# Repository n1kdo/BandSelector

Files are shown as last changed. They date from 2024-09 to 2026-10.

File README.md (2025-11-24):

# N1KDO IOT Band Selector for Elecraft K3 & K4 

This project is intended to operate a remote antenna switch.

How is it different from commercial-off-the-shelf solutions?
* Direct interface with Elecraft 15-Pin accessory interface. It reads
  BCD band data using the Elecraft Y-cable or a device like a Y-box.
  * provides transmit inhibit and power-on sense/control.
  * it's not designed for other radios.  Tested on Elecraft only. It _should_ 
    work with other radios that use similar BCD active low band signaling. 
* Wireless! It runs over Wi-Fi, connect the band selector to 
  the 15-pin accessory connector, and supply DC to the coaxial
  power jack. 
* Automatic TX Inhibit prevents TX into wrong/no antenna.
* Automatic power-up of K3 and K4 radios using accessory connector pin.  The
  band selector can be configured to automatically power up a attached K3 or K4 
  10 seconds after the Band Selector powers up.
* Smart antenna selection based on band.  If you have more than one antenna
  for a given band, the logic selects the antenna that matches the fewest
  other bands, which is hopefully the best fit.  If that antenna is in use by
  the other radio, then it selects the next-best match.  When more than one
  antenna is available for the given band, the front panel Next/Prev buttons
  let you select other antennas that support the selected band.
* Inexpensive (relatively) compared to existing commercial solutions. 
  About 77 USD for each band selector, if you build one or two yourself.
  (Circuit boards come in threes from Oshpark.)  The 
  [Antenna Switch Controller](https://github.com/n1kdo/AntennaSwitchControl) 
  costs about 106 USD; the most expensive part is the 
  [DXE-RR2X8B 2x8 remote controlled switch](https://www.dxengineering.com/parts/DXE-RR2X8B),
  which is not inexpensive at 669 USD.
* Open Source Hardware and Software.  Do what you will with attribution.

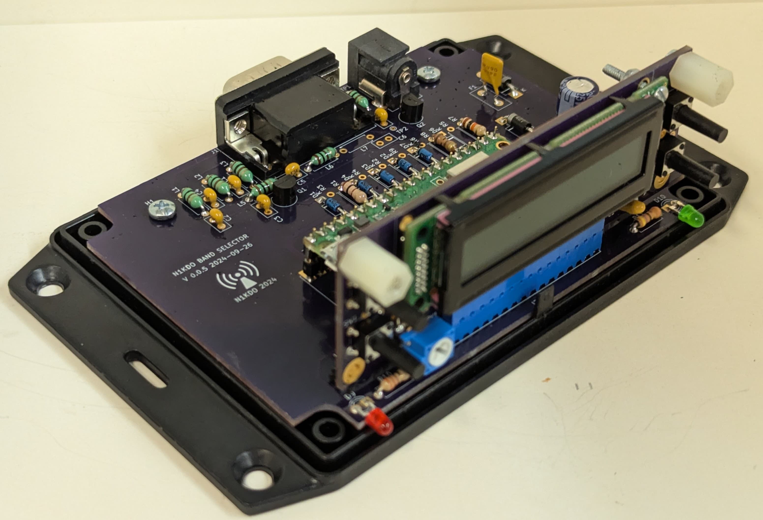
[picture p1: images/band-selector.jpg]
Band Selector
 Band Selector

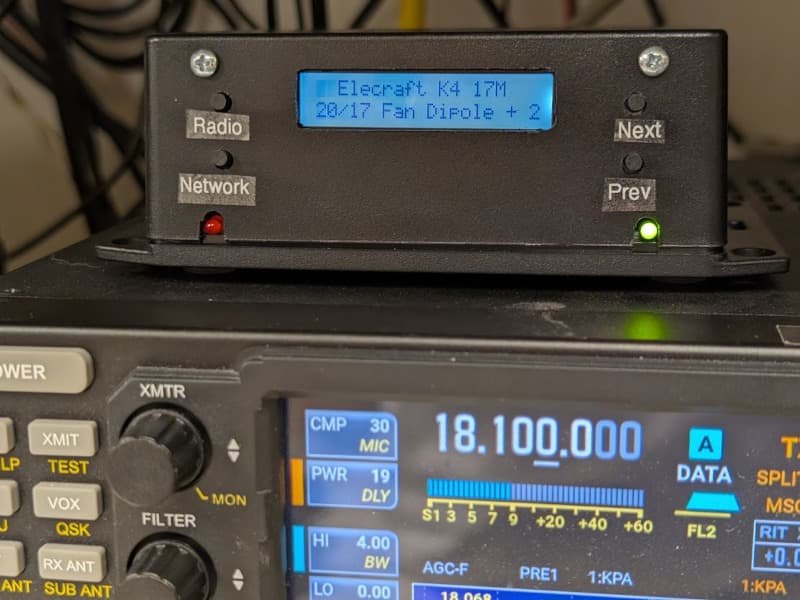
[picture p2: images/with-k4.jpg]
With K4 Interfaced with K4
 Interfaced with K4

# How it works

Each of two Elecraft K3 or K4 radios is connected to a Band Selector, which
is also provided DC power.  That is all the wiring that is needed at the radio.

The Band Selectors both communicate with a
[Antenna Switch Controller](https://github.com/n1kdo/AntennaSwitchControl), 
which provides control voltage steering to a antenna switch.  

The project is in two pieces:

  * The [Antenna Switch Controller](https://github.com/n1kdo/AntennaSwitchControl) provides a IOT endpoint for managing a 2x6 or 2x8
    antenna switch: https://github.com/n1kdo/AntennaSwitchControl
  * The Band Selector interfaces with a K3 or K4 radio, and provides the following functions:
    * Decodes selected bands from Elecraft radio AUX jack.
    * Requests antenna from the controller.
    * If the requested band antenna cannot be selected, activate the radios' TX INHIBIT
      logic to prevent transmit.
    * The Band Selector includes a 2nd circuit board for the display.
  
This repository contains the hardware and software for The Band Selector: 
  * `kicad` folder contains the electronic design.
  * `src` folder contains the software.
  * [Bill of Materials](BOM.md "Bill of Materials")

# Ecosystem

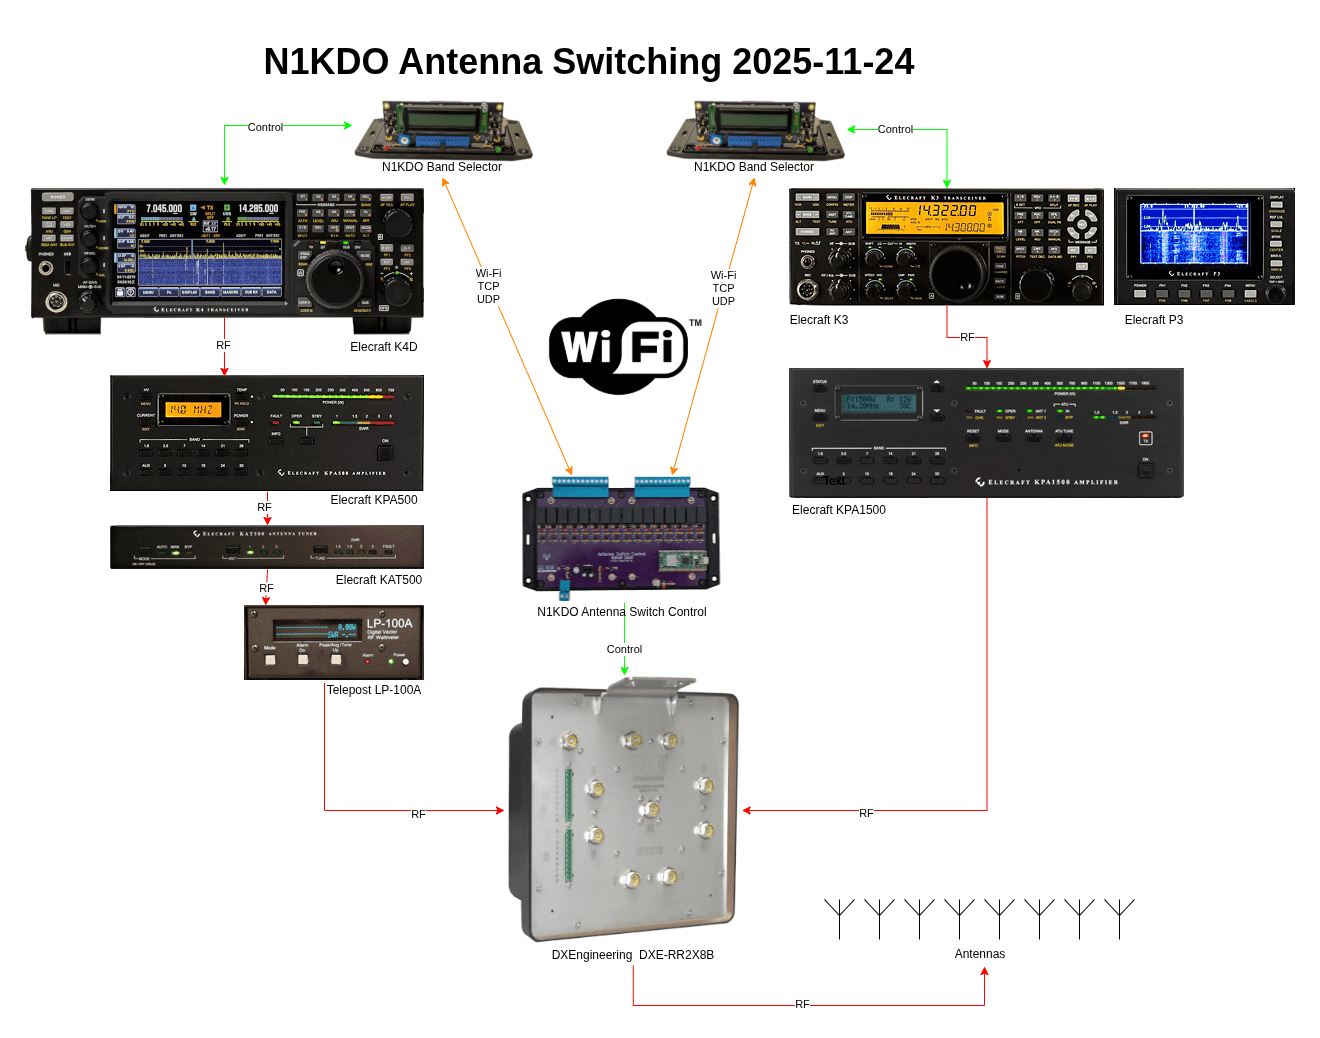
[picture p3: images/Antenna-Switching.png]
Band Selector Ecosystem Antenna Switching Ecosystem
 Antenna Switching Ecosystem

## Setup

  * Connect the BandSelector to the K3/K4 using the 15-pin "y" cable supplied by
    Elecraft.  Band select data and power status will be communicated to the 
    BandSelector.
  * Connect the BandSelector to 10-15 volts DC via the rear panel power jack 
    which accepts a 2.00mm ID, 5.50mm OD coaxial power plug, center positive.

### Setup TX Inhibit

If the band selector cannot grant access to an appropriate antenna for the
band selected on the radio, it can "inhibit" transmit on the radio, which
is useful for protecting the transmitter and amplifier from damage due to 
antenna mismatch.

When the BandSelector inhibits transmit, the red LED on the lower left
of the front panel will light.

The radios must be configured to accept the inhibit input from the 
Band Selector.  Instructions for K3 and K4 are below.  The electrical
interface from the Band Selector is an "open drain" from a 2N7000 MOSFET.

  * On a K3, locate the "TX INH" option in the "CONFIG" menu.  
    Set this option to "LO=Inh".  
    When transmit is inhibited, the "TX" indicator (right side of
    display, between the A and B VFO labels) will blink.
  * on a K4, locate the "TX Inhibit Mode" option in "MENU".  
    Set this option to "LO=Inhibit".  
    When transmit is inhibited, the TX label (top center of display)
    will display "TX Inh".

# User Interface

In addition to the front panel controls (4 buttons and a 2x20 LCD display), the 
Band Selector has a web UI for configuration and management.

## Band Selector Status Page
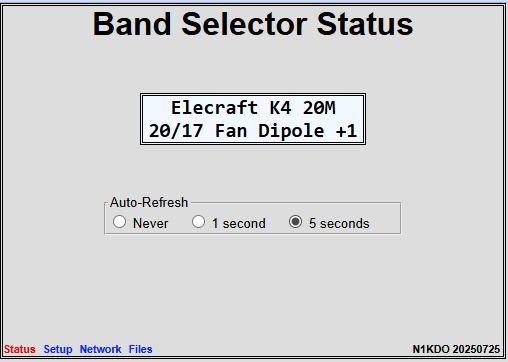
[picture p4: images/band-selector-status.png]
Status Page Band Selector Status Page
  

## Band Selector Networking Page
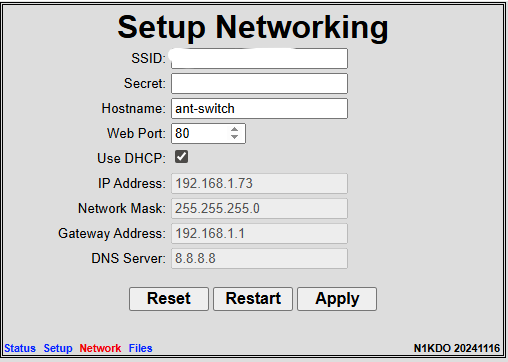
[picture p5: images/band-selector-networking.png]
Network Setup Page Band Selector Networking Page
  

## Band Selector Configuration Page
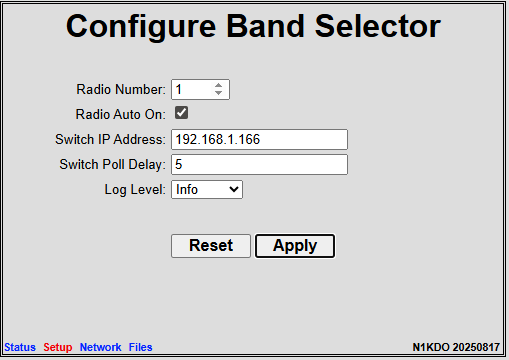
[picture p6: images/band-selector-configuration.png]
Status Page Band Selector Configuration Page
  

# License

The software is licensed under [BSD "2-Clause" license](Software-License.md), 
_except as where noted._

The hardware is licensed under terms of the 
[Creative Commons Attribution-ShareAlike 4.0 
International Public License.](Hardware-License.md)

20251124 n1kdo

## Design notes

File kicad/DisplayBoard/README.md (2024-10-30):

# display-board

This is a carrier for a 2x20 LCD display.  It has 4 pushbuttons that are
pull-to-ground.

The module is intended to mount in the front part of the cover of a Hammond
1591XXSFLBK enclosure.  Note that I have not actually tried this yet.

The board has a cut-out for the visible part of the display, and holes marking
all the pushbutton actuators.  The intent is that a bare board can be used as a 
template to mark the enclosure for drilling.

3d mockup from Kicad:

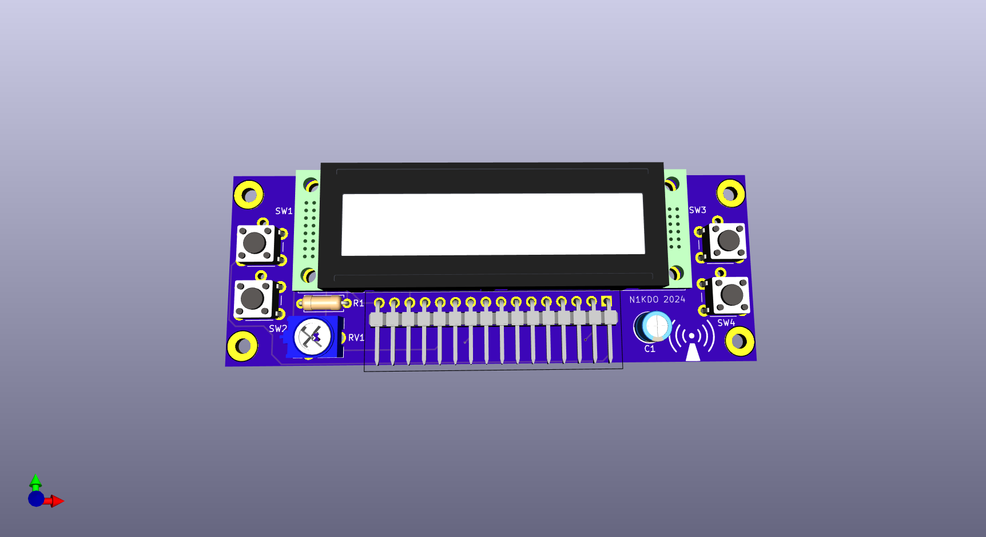
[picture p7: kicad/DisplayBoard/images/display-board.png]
Display Board.


Prototype 1:

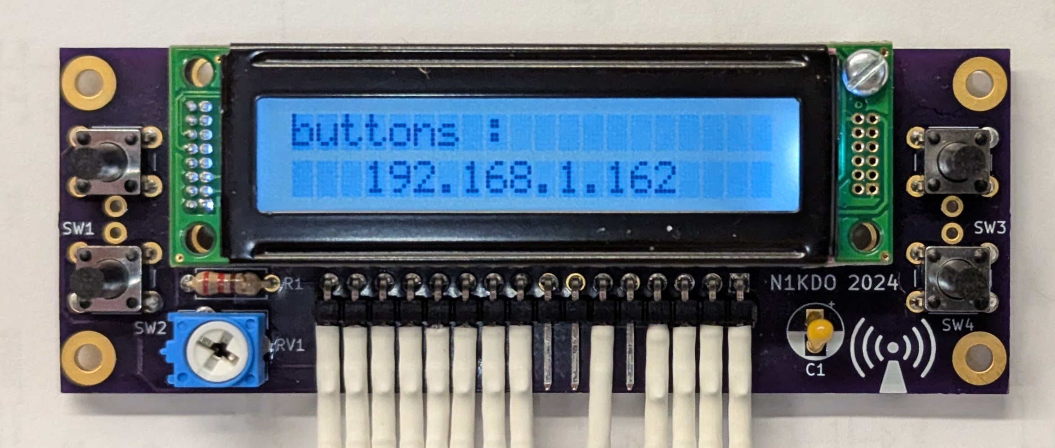
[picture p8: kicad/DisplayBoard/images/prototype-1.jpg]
Display Board.


Design PDFs

[Schematic PDF](display-board.kicad_sch.pdf)

[Layout PDF](display-board.kicad_pcb.pdf)

* cad_models contains the downloaded vendor assets for symbols, footprints, 3-d models

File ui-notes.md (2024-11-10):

# UI Design Nodes for N1KDO Band Selector

## Front Panel Layout 

(O) is a button.

```
+------------------------------------------------+
|                                                |
| Menu  O   +----------------------+      O ↑    |
|           | 2 x 20 alphanumeric  |             |
|           | 12345678901234567890 |             |
| Edit  O   +----------------------+      O ↓    |
|                                                |
+------------------------------------------------+
```

## Switch to Button Assignments

| Switch | Function |
|---|---|
| SW1 | Menu |
| SW2 | Edit |
| SW3 | Up |
| SW4 | Down |

## Navigation and Editing

The _Menu_ button enters "Menu" mode.

When in menu mode, the up/down buttons select the next or prior display option.

If a value is editable, the _name_ of the value is shown on the top line, and the
_value_ of the item is shown on the bottom line.

To edit a value, press the "edit" button.  Now the up/down buttons will scroll 
through the lit of available options for that value.  Press "edit" to accept the
currently shown value, or press "menu" to revert to the saved value.

When *not* in "menu mode", the 2x2o display shows the radio status:

* the top line displays the radio name and selected band.
* the bottom line displays the selected antenna.

When *not* in menu mode, the up/down buttons can be used to select other 
antennas that are compatible with the current band.

When *not* in menu mode, the "edit" button will cause the network configuration
to be shown on the display.

## Menu State Machine(s)

| State Number | Function | Const |
|:---:|:---|---|
| 0 | Display Radio Status | RADIO_STATUS_STATE |
| 1 | Display Network Status | NETWORK_STATUS_STATE |
| 20x | Menu Mode, display menu item X | MENU_MODE_STATE_BASE |
| 30x | Menu Mode, edit menu item X | MENU_EDIT_STATE_BASE |
| | TBD? | |

### State 0  -- Display Radio Status

In this state the display shows two lines:

* Radio Name and Band
* Selected Antenna

Actions from this state:

| Button | Action |
|:---|:---|
| Menu | Switch to state 20x | 
| Edit | Update Display to Network Status <br>Switch to state 1. |
| Up | switch to next compatible antenna |
| Down | switch to prior compatible antenna | 

## State 1 -- Display Network Status

In this state the display shows two lines:

* Network SSID
* IP address of device

All actions from this state return to the radio status state (0).

| Button | Action | Function |
|:---|:---|:---|
| Menu | Update display to radio status<br>Switch to state 0. | Return to Radio Status | 
| Edit | Update display to radio status<br>Switch to state 0. | Return to Radio Status | 
| Up | Update display to radio status<br>Switch to state 0. | Return to Radio Status | 
| Down | Update display to radio status<br>Switch to state 0. | Return to Radio Status | 

### State 20x  -- Menu Mode, Display Item X

In this state the display shows two lines:

* Menu Item _Name_
* Menu Item _Value_

Actions from this state:

| Button | Action | Function |
|:---|:---|:---|
| Menu | Update display to radio status<br>Switch to state 0. | Return to Radio Status | 
| Edit | Switch to state 30x. | Enter Edit Value Mode  |
| Up | switch to next menu item | Next Item |
| Down | switch to prior menu item | Previous Item |

### State 30x -- Edit Mode, Edit Item X

In this state, the display shows two lines:

* Menu Item _Name_
* Menu Item _Value_

If the cursor can be show blinking on line 2, that would be great.

| Button | Action | Function |
|:---|:---|:---|
| Menu | Switch to state 20x. | Abandon Edit | 
| Edit | Save Data.<br>Switch to state 20x. | Save Edit |
| Up | switch to next menu item _value_ | Next Item Value |
| Down | switch to prior menu item _value_  | Previous Item Value |

## Configuration Options accessible from the menu.

Access Point Mode: Access Point or Station
Restart Mode: Yes or No

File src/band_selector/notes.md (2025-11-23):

# Implement Message Queue.  (DONE)
  messages drive actions

  ## Message types

  * buttons 1-4 falling edge: control UI functions.
  * pwrsense change.  can choose to turn on radio.
  * band change.  send to band logic
  * http responses -- valid
    * band request responses
    * information request responses
  * http responses -- failures
    * timeout or unreachable
  * update display, write, home, clear, moveto, cursor on/off, value up/down?
  * timer event

implement task that reads hardware inputs:

* buttons 1-4 -- either edge
* PWRSENSE -- either edge
* band data b0-b3 collectively as 4-bit value 0-F -- send event on edge
* 
send message into message queue

implement task that runs async http transaction, enqueues result

implement task (?) to update display?  
do I need this?  all fast except clear and home, they need 5 ms.

Make the message a tuple.  in many cases, the message will be a 1-tuple, if 
there is such a thing.  In other cases, additional data may be references by
2nd (and subsequent) tuple values.

## messages by ID:

1, 2, 3, 4: button ID, 2nd part of tuple is short (0) or long (1) press
10: pwrsense, 2nd value is hi/lo
20-2x: network status messages, (code, text) -- is this used?
50: network down/up message, (50, 0|1)  **NOT USED**

90, 91, write LCD line 0,1 (9x,text)
100: band change, 2nd value is new band #
201 api status response, text in 2nd value of tuple
202 api select antenna, text in 2nd value of tuple
1000+: timer events.  

# Display update process.

Concept: the display should show the radio/band/current antenna as the default.

The current access point and IP should also be available. if the network is not connected,
or there is no connection to the antenna switch, that message should have highest priority.

Network status change messages (connecting, failed, connected) should pop up for N seconds.

menu buttons:
```
                  +------------------------------+
                  |   +----------------------+   |
    radio status  | o | 123456 Line 1 567890 | o |  ^ antenna up
  network status  | o | 123456 Line 2 567890 | o |  v antenna down
                  |   +----------------------+   |
 red LED inhibit  |  *                        *  |  green LED power
                  +------------------------------+

```

some? message updates set a timer to make that 2-line 'page' of pop that
message to the top for N seconds,  
button activity resets timeout,   
but menu change may update display and set timeout
a timeout reset causes last message (stack or 2-deep?) to be shown.

## Display Messages:

### Network

Display WiFi net name and IP address.

```
12345678901234567890
  Free Public Wifi  
    192.168.0.201       
```

### Radio

Display radio name and Band and Antenna Name

```
12345678901234567890
  Elecraft K3 40M  
  40 Meter Dipole         
```

* add + plus sign after antenna name if there is another antenna available... DONE
  * up/down buttons select antenna only when this page is displayed

### Activity

* other messages:  
  * Network
     * "Connecting to WLAN..."  
     * "setting hostname / ant-switch"  
     * "connecting to / fbi surveillance van"
  * Radio
    * "Unknown Rig No Power"  
    * / Unknown Antenna  
    * / "No Antenna Switch!" -- cannot reach antenna switch

### Menu:

* can menu go away?  YES DONE  
* right now there is an option for station or access point. REMOVED.  
  * disable config change of ap_mode. DONE
  * when not in ap_mode, disable config ssid & password write  
    * exactly how much to disable? hostname? dhcp? dns?  
* use held button at powerup to set ap_mode -- must have access to hardware.
  * hold down switch 1 at power up to select AP/setup mode. DONE.

### Config

* make config into Config class and encapsulate functions? LATER

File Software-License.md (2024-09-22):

# BSD 2-Clause License

**Copyright (c) 2024, Jeffrey B. Otterson, N1KDO**

All rights reserved.

Redistribution and use in source and binary forms, with or without
modification, are permitted provided that the following conditions are met:

* Redistributions of source code must retain the above copyright notice, this
  list of conditions and the following disclaimer.

* Redistributions in binary form must reproduce the above copyright notice,
  this list of conditions and the following disclaimer in the documentation
  and/or other materials provided with the distribution.

**THIS SOFTWARE IS PROVIDED BY THE COPYRIGHT HOLDERS AND CONTRIBUTORS "AS IS"
AND ANY EXPRESS OR IMPLIED WARRANTIES, INCLUDING, BUT NOT LIMITED TO, THE
IMPLIED WARRANTIES OF MERCHANTABILITY AND FITNESS FOR A PARTICULAR PURPOSE ARE
DISCLAIMED. IN NO EVENT SHALL THE COPYRIGHT HOLDER OR CONTRIBUTORS BE LIABLE
FOR ANY DIRECT, INDIRECT, INCIDENTAL, SPECIAL, EXEMPLARY, OR CONSEQUENTIAL
DAMAGES (INCLUDING, BUT NOT LIMITED TO, PROCUREMENT OF SUBSTITUTE GOODS OR
SERVICES; LOSS OF USE, DATA, OR PROFITS; OR BUSINESS INTERRUPTION) HOWEVER
CAUSED AND ON ANY THEORY OF LIABILITY, WHETHER IN CONTRACT, STRICT LIABILITY,
OR TORT (INCLUDING NEGLIGENCE OR OTHERWISE) ARISING IN ANY WAY OUT OF THE USE
OF THIS SOFTWARE, EVEN IF ADVISED OF THE POSSIBILITY OF SUCH DAMAGE.**

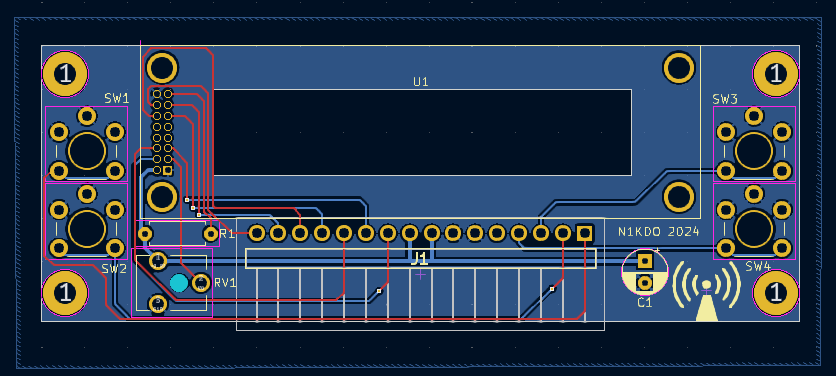
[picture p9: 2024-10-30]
kicad/DisplayBoard/images/pcb-layout.png

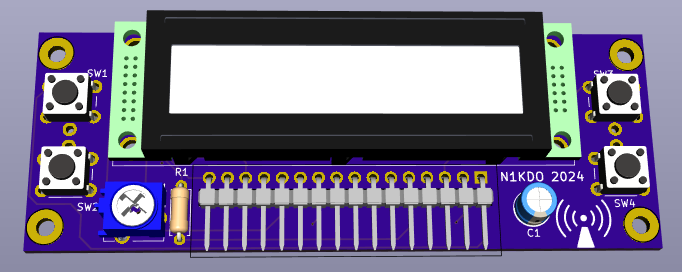
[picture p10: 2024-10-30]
kicad/DisplayBoard/images/display-board-3d-0.0.3.png

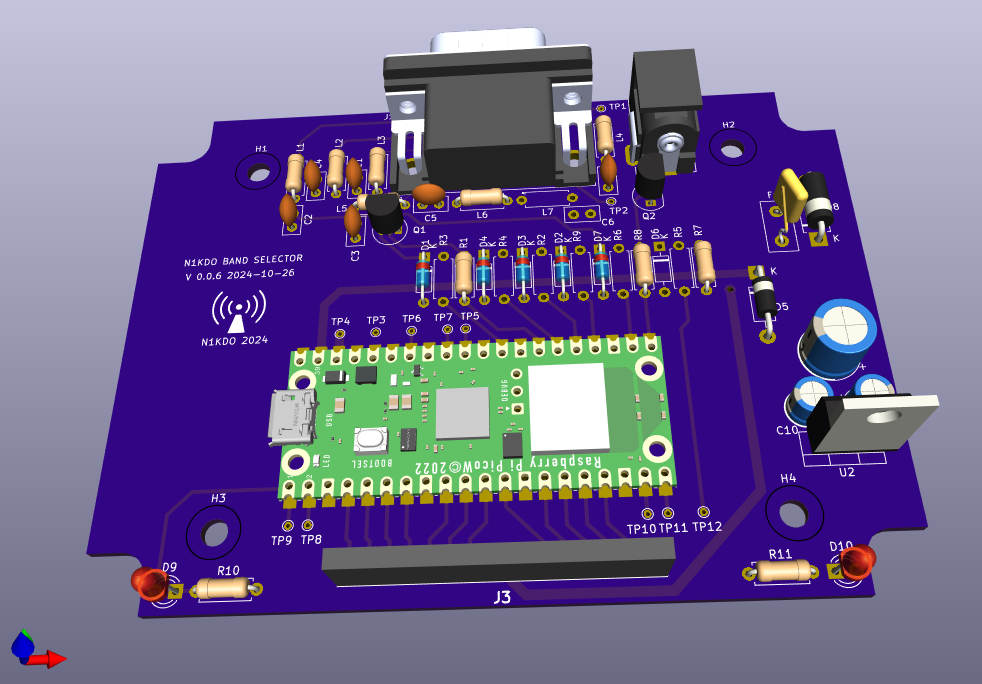
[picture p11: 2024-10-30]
kicad/BandSelector/images/3d-render.png

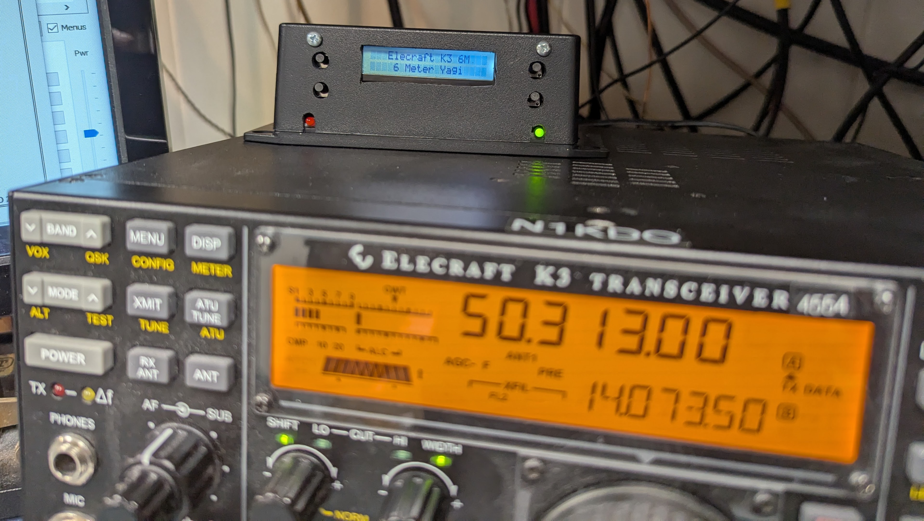
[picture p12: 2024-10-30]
images/with-k3.jpg

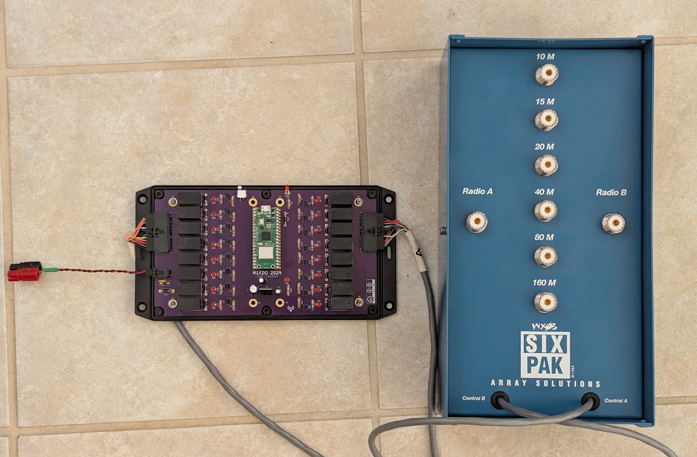
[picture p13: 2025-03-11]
images/antenna-switch-control.jpg

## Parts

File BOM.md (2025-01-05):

# Bill of Materials for Band Selector

This is the Bill of Materials for the N1KDO Band Selector.

All the parts -- except the circuit boards -- were ordered from Mouser.com.

The circuit boards came from Oshpark.com.

Costs are approximate, they were checked 2025-01-05.  

## Display Board Bill of Materials

| id | desc | mfg | part | qty | price | ext |
|---|---|---|---|----:|---:|---:|
| C1 | 1 uF 35 V tantalum | Vishay | 199D105X9035A2B1E3 | 1 |  1.76 | 1.76 |
| J1 | 1x16 right angle sip connector | Molex | 22-28-8160 | 1 |  1.40 | 1.40 |
| R1 | Carbon Film Resistors - Through Hole 1/4W 220 Ohm 5% | Yageo | CFR-25JB-52-220R | 1 |  0.10 | 0.10 |
| RV1 | 10K ohm trim pot | Amphenol Piher | N6-L50T0C-103 | 1 |  0.72 | 0.72 |
| SW1, 2, 3, 4 | Tactile Pushbutton | Same Sky | TS02-66-130-BK-100-LCR-D  | 4 |  0.14 | 0.56 |
| U1 | 2x20 backit LCD display 3.3 volt | New Haven Display | NHD-0220FZ-FSW-GBW-P-33V3 | 1 | 12.66 | 12.66 |
| PCB | N1KDO Display Board PCB V 0.0.4 | | Oshpark | 1 |  7.30 | 7.30 |
| **Total** | | | | | | **24.50** |

## Main Board Bill of Materials

| id | desc | mfg | part | qty | price | ext |
|---|---|---|---|----:|---:|---:|
| C1,C2,C3,C4,C5,C7 | 50V 0.1uF X7R 10% LS =2.54mm | KEMET | C320C104K5R5TA | 6 |  0.17 | 1.02 |
| C6 | (DNP) 50V 0.1uF X7R 10% LS =2.54mm | KEMET | C320C104K5R5TA | 1 |  0.17 | 0.00 |
| C8 | Aluminum Electrolytic Capacitors - Radial Leaded 220uF 25V | Panasonic | ECA-1EM221 | 1 |  0.28 | 0.28 |
| C9,C10 | Aluminum Electrolytic Capacitors - Radial Leaded 2.2uF 50volts AEC-Q200 | Panasonic | EEU-FC1H2R2H | 2 |  0.24 | 0.48 |
| D1,D2,D3,D4,D7 | Schottky Diodes & Rectifiers 200mA 30 Volt | STMicroelectronics | BAT43 | 5 |  0.17 | 0.85 |
| D5 | Schottky Diodes & Rectifiers Vr/40V Io/1A | STMicroelectronics | 1N5819 | 1 |  0.21 | 0.42 |
| D6 | (DNP) Schottky Diodes & Rectifiers 200mA 30 Volt | STMicroelectronics | BAT43 | 1 |  0.17 | 0.00 |
| D8 | Rectifiers Diode, DO-41, 100V, 1A | Diotec | 1N4002 | 1 |  0.06 | 0.06 |
| D9 | Standard LEDs - Through Hole Green Diffused | Lite-On | LTL-4231N | 1 |  0.13 | 0.13 |
| D10 | Standard LEDs - Through Hole Red Diffused | Lite-On | LTL-4221N | 1 |  0.19 | 0.16 |
| F1 | Resettable Fuses - PPTC .9A 30V 100A Imax | LittelFuse | RUEF090 | 1 |  0.61 | 0.61 |
| J1 | D-Sub High Density Connectors 15P MALE R/A PIN UNC 4-40 CLINCH NUTS | Amphenol FCI | 10090926-P154XLF | 1 |  1.65 | 1.65 |
| J2 | DC Power Connectors RT ANGL PWK JK PIN D | Switchcraft | RAPC722X | 1 |  2.21 | 2.21 |
| J3 | Board to Board & Mezzanine Connectors 16P VRT SR RECEPT MATTE TIN | Amphenol FCI | 75915-416LF | 1 |  2.41 | 2.41 |
| L1,L2,L3,L4,L5,L6 | RF Inductors - Leaded RF CHOKE 100uH 5% CONFORMAL COATED | Bourns | 78F101J-TR-RC | 6 |  0.18 | 1.08 |
| L7 | (DNP) RF Inductors - Leaded RF CHOKE 100uH 5% CONFORMAL COATED | Bourns | 78F101J-TR-RC | 0 |  0.18 | 0.00 |
| Q1,Q2 | MOSFETs Small Signal MOSFET 60V 200mA 5 Ohm Single N-Channel TO-92 | onsemi / Fairchild | 2N7000 | 2 |  0.38 | 0.76 |
| R1,R8 | Carbon Film Resistors - Through Hole 1/4W 100 Ohm 5% | Yageo | CFR-25JB-52-100R | 2 |  0.04 | 0.08 |
| R2,R3,R4,R5,R6,R9 | Carbon Film Resistors - Through Hole 1/4W 10K Ohm 5% | Yageo | CFR-25JB-52-10K  | 6 |  0.02 | 0.10 |
| R10 | Carbon Film Resistors - Through Hole 1/4W 330 Ohm 5% | Yageo | CFR-25JB-52-330R | 1 |  0.02 | 0.02 |
| R11 | Carbon Film Resistors - Through Hole 1/4W 470 Ohm 5% | Yageo | CFR-25JB-52-470R | 1 |  0.02 | 0.02 |
| U1 | Single Board Computers Raspberry Pi Pico W | Raspberry Pi | SC0918 | 1 |  6.00 | 6.00 |
| U2 | Linear Voltage Regulators 5.0V 1.5A Positive | STMicroelectronics | L7805CV | 1 |  0.48 | 0.48 |
| PCB | N1KDO Band Selector Board PCB V 0.0.4 | Oshpark | | 1 | 21.20 | 21.20 |
| Enclosure | Enclosures, Boxes, & Cases FR ABS w/Flanged Lid 7.6x4.4x2.2" Black | Hammond Manufacturing | 1591XXEFLBK | 1 | 12.89 | 12.89 |
| **Total** | | | | | | **52.91** |

Total Band Selector approximate cost about $77/radio. (24.50 + 52.91)

n1kdo 20250105

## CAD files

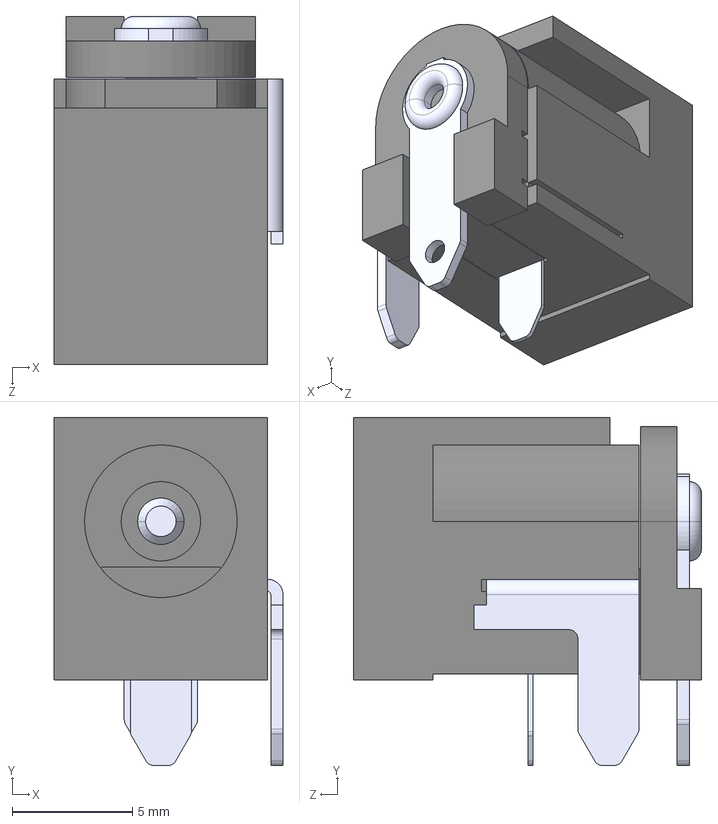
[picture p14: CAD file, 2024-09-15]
kicad/BandSelector/3d/RAPC722X.step
9.53 x 14.5 x 14.5 mm

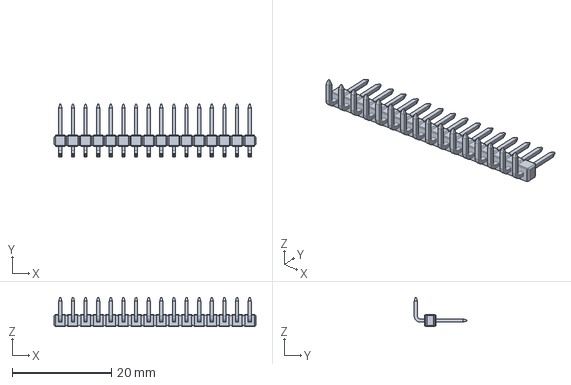
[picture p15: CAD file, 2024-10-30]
kicad/DisplayBoard/3d/22-28-8160.stp
40.6 x 10.6 x 5.92 mm

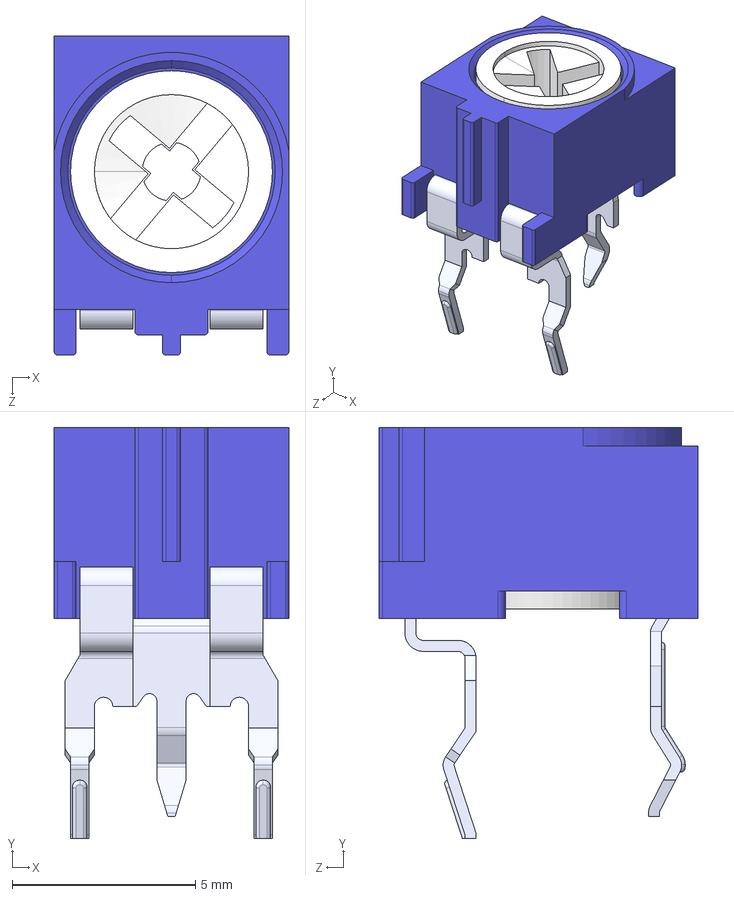
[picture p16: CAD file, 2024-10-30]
kicad/DisplayBoard/3d/N6-L50T0C-103.stp
6.40 x 11.2 x 8.70 mm

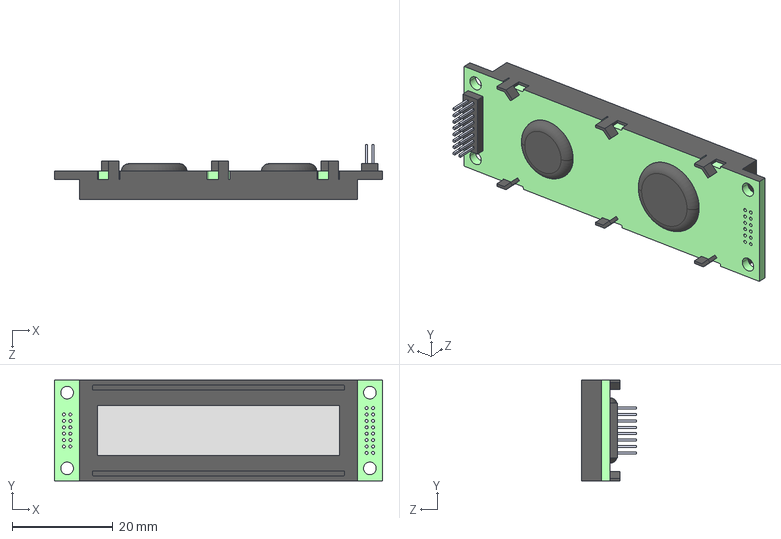
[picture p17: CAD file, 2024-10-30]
kicad/DisplayBoard/3d/NHD-0220FZ-FSW-GBW-P-33V3.stp
65.0 x 20.0 x 10.9 mm

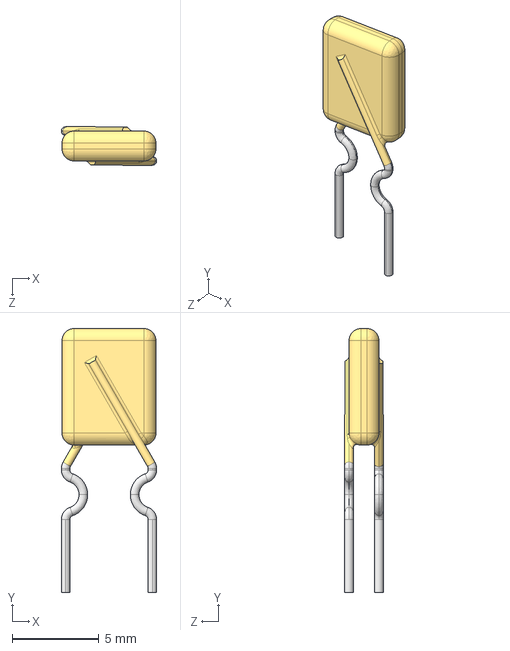
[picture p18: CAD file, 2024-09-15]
kicad/BandSelector/3d/RUEF090.step
5.50 x 15.2 x 2.22 mm

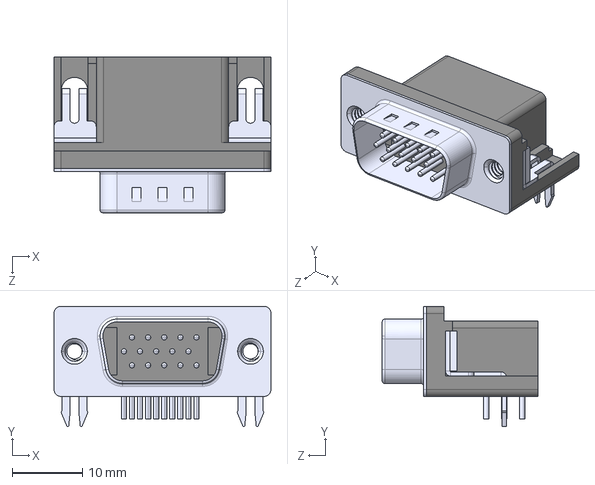
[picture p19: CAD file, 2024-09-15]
kicad/BandSelector/3d/10090926-P154XLF.step
30.8 x 17.1 x 22.1 mm

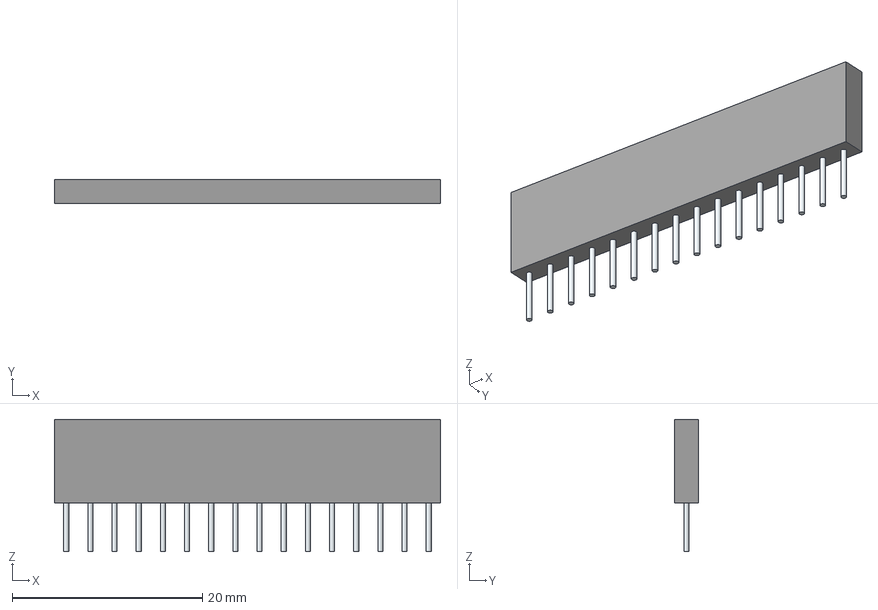
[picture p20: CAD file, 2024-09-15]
kicad/BandSelector/3d/75915-416LF.step
40.6 x 2.50 x 13.9 mm
Leads

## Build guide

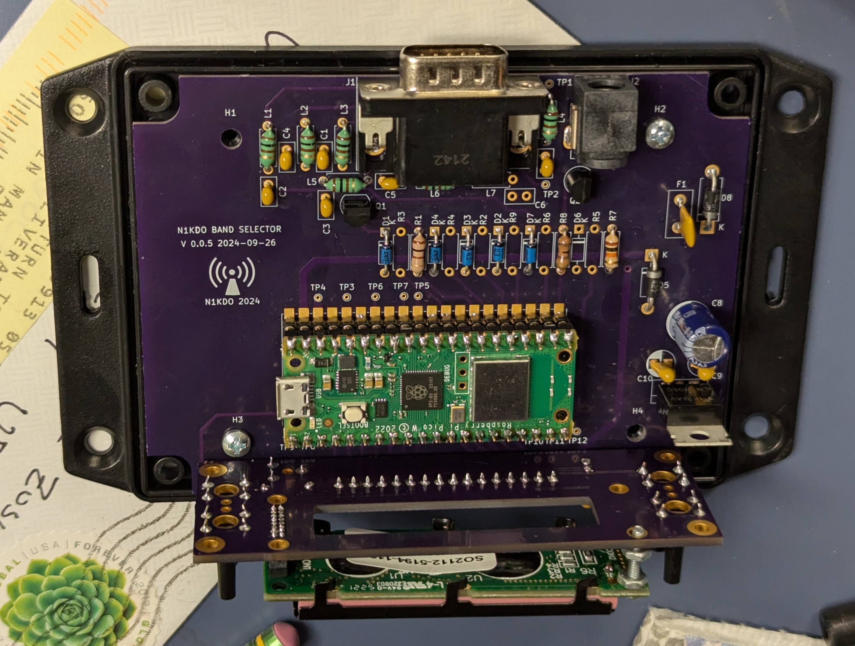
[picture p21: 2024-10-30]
kicad/BandSelector/images/board-with-display-board-installed.jpg

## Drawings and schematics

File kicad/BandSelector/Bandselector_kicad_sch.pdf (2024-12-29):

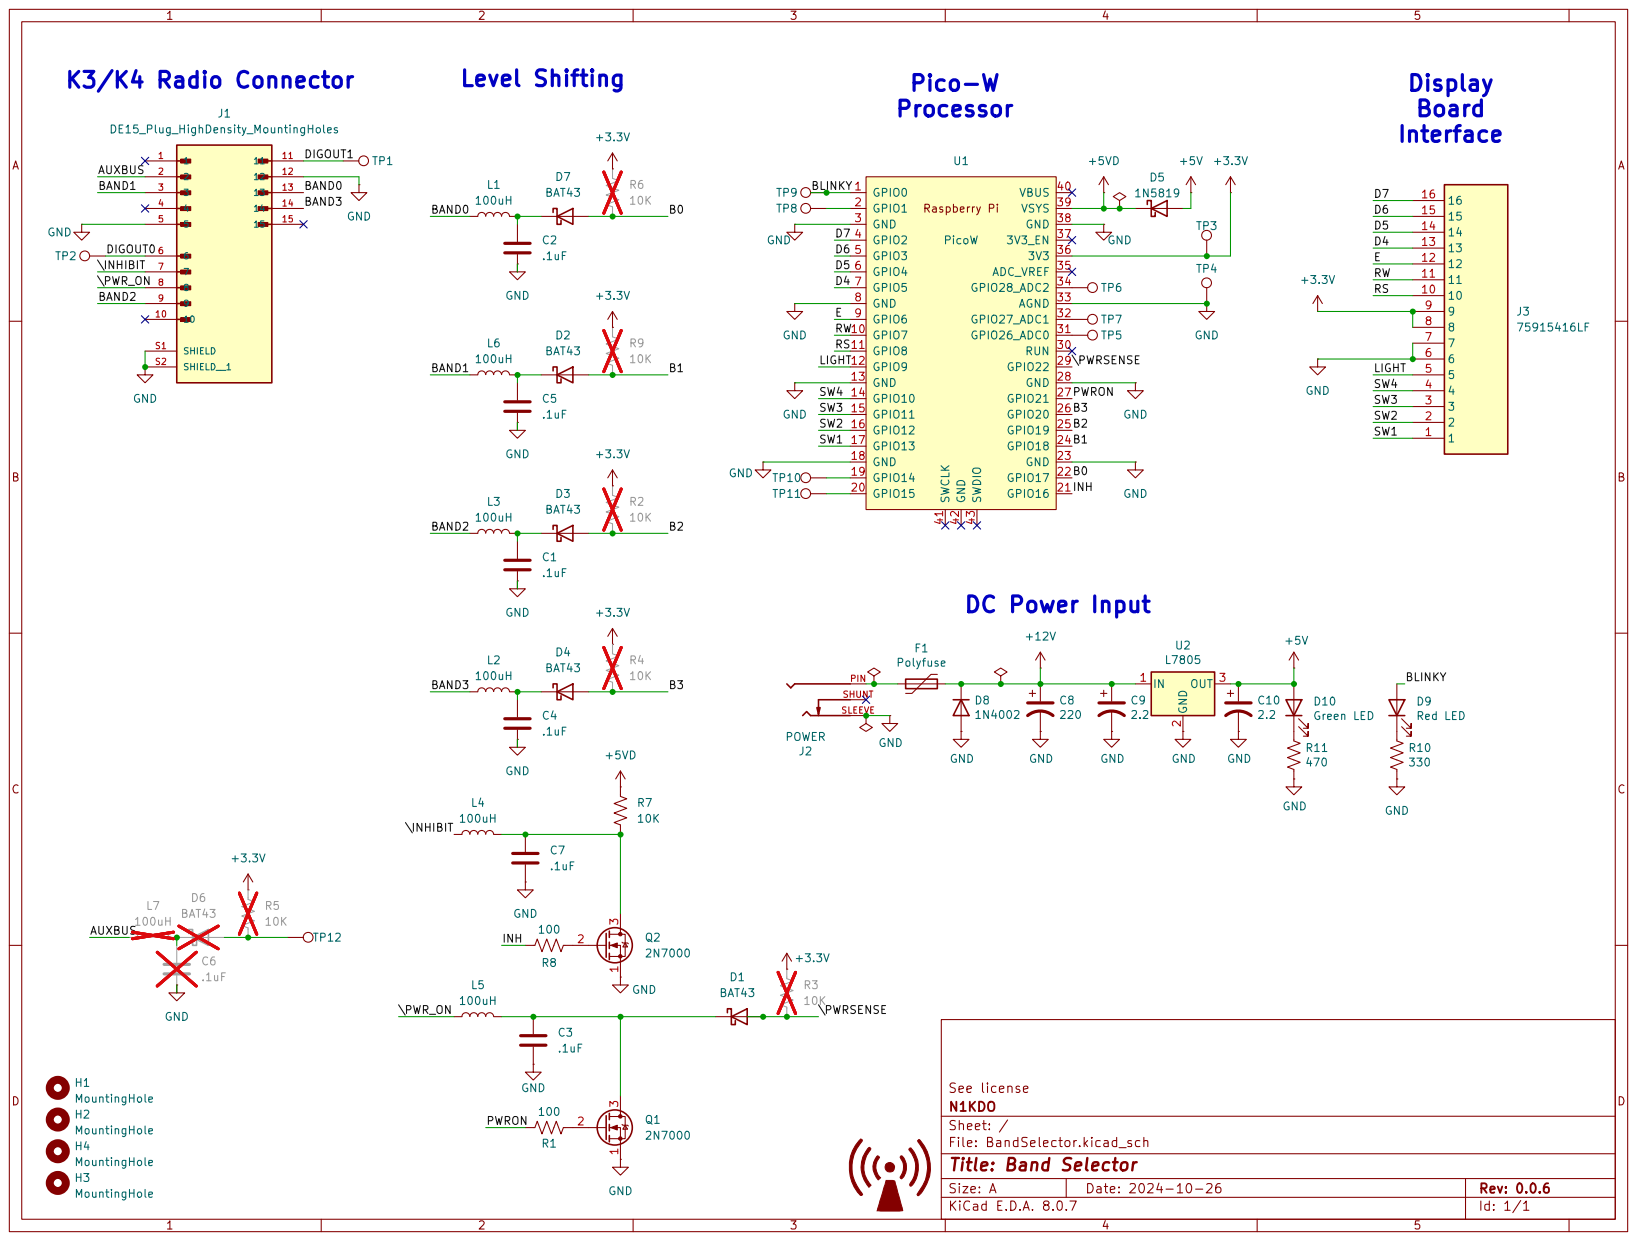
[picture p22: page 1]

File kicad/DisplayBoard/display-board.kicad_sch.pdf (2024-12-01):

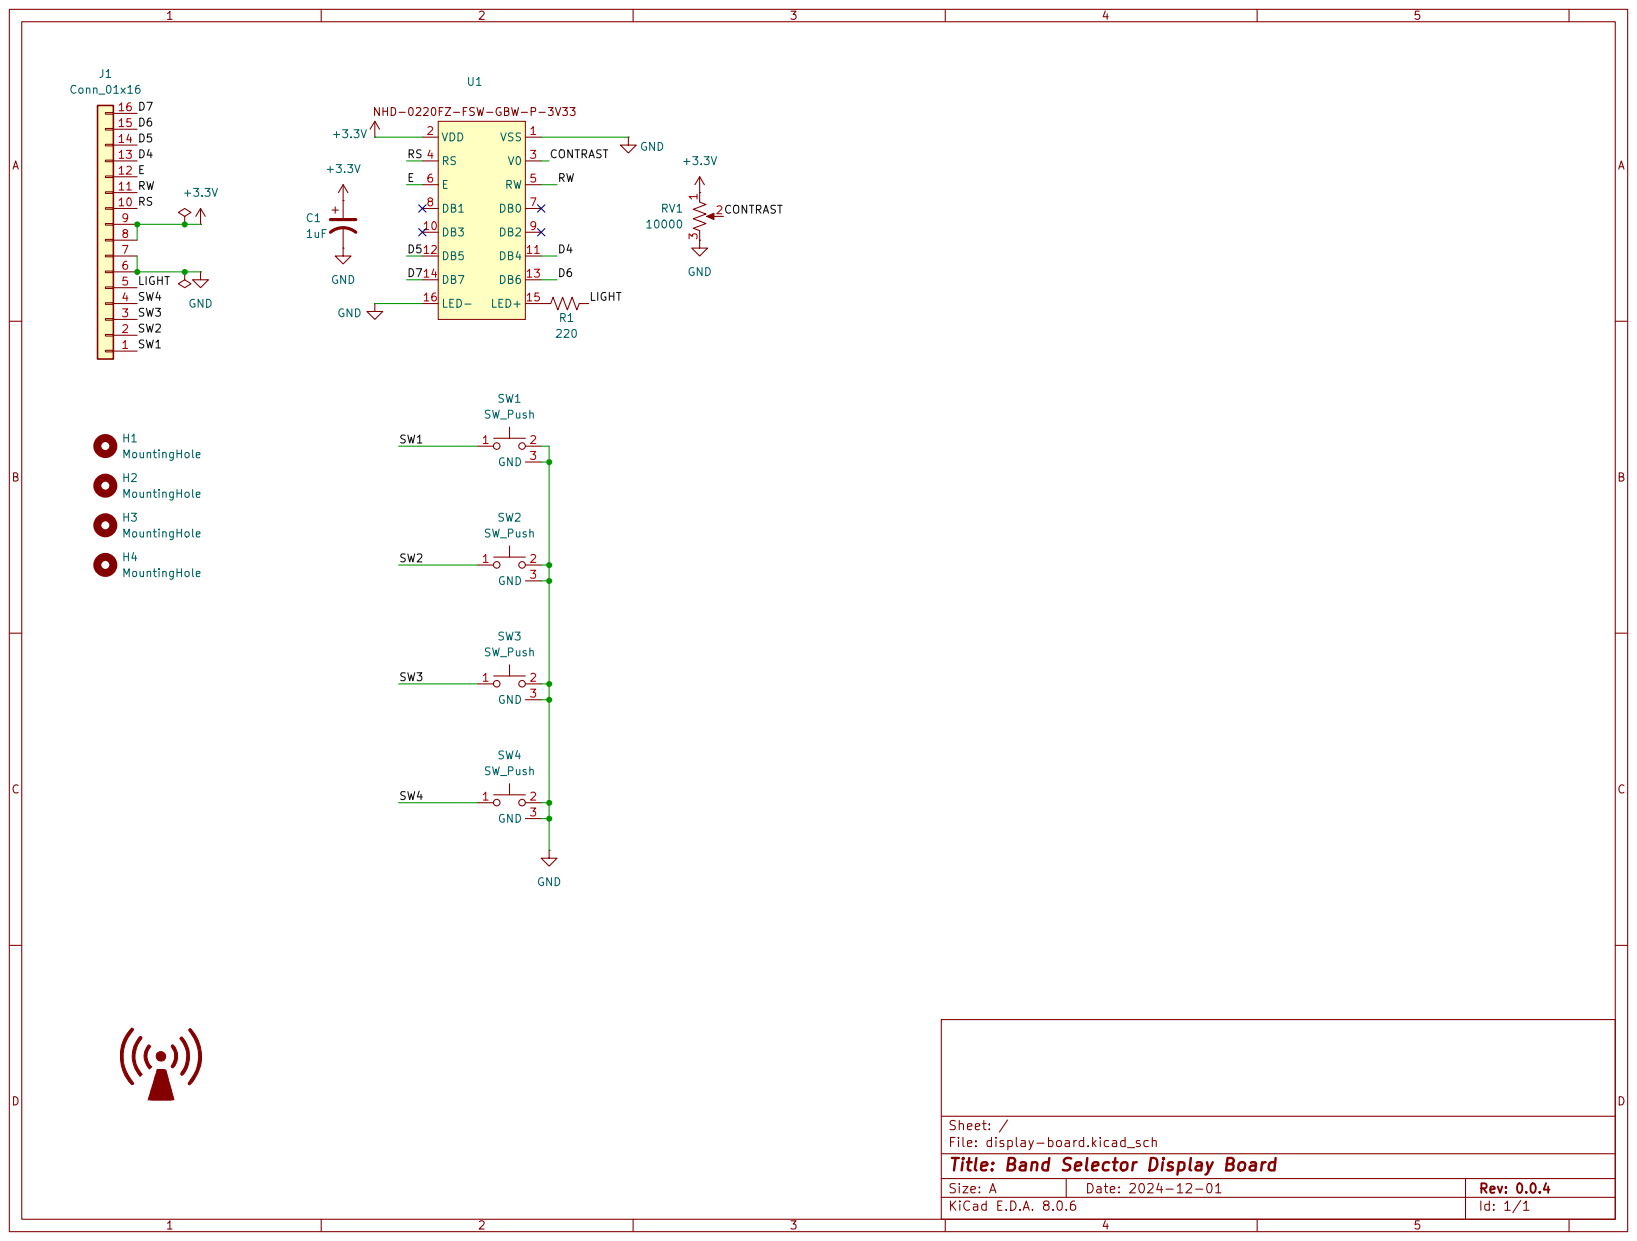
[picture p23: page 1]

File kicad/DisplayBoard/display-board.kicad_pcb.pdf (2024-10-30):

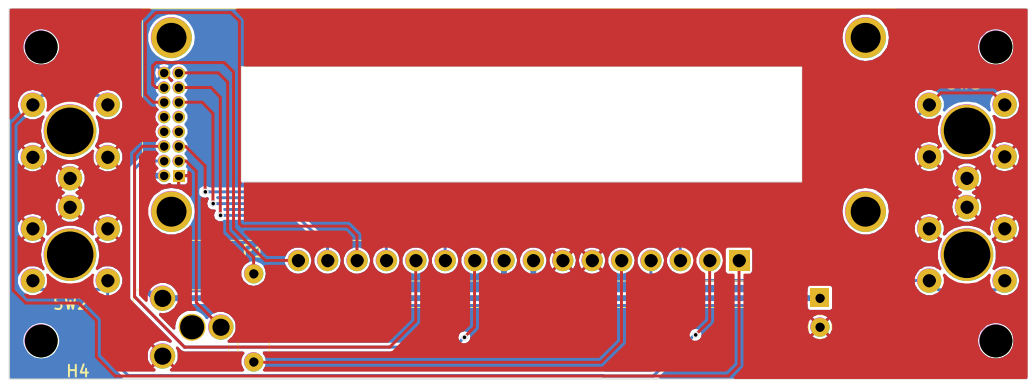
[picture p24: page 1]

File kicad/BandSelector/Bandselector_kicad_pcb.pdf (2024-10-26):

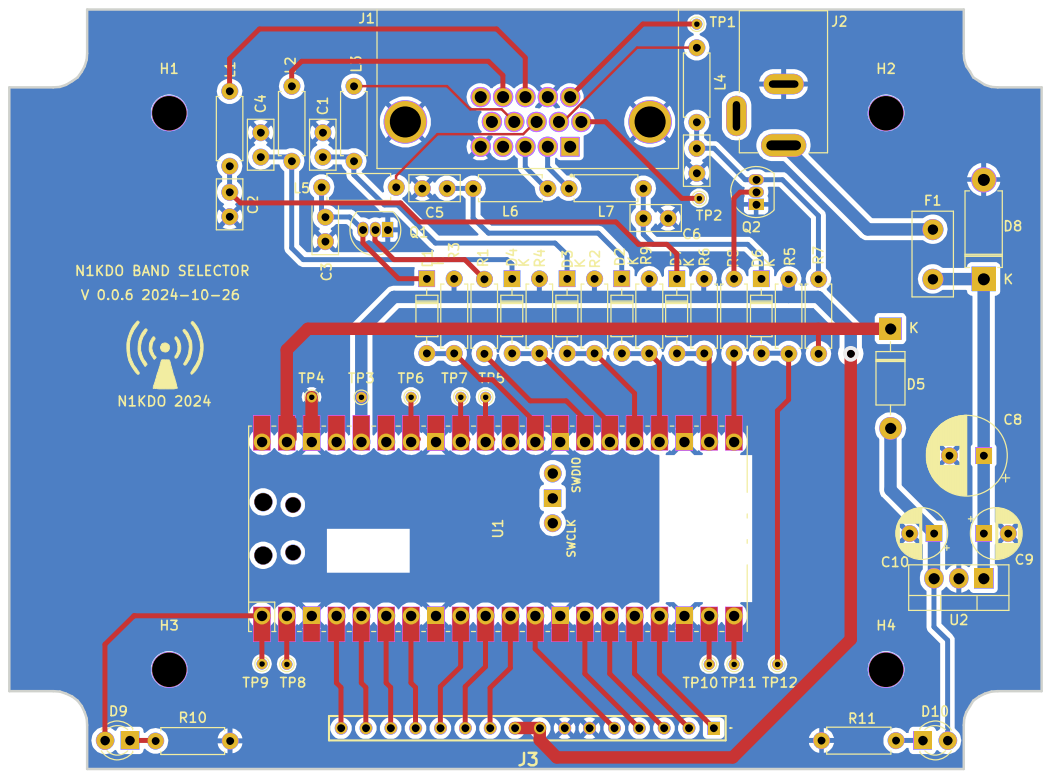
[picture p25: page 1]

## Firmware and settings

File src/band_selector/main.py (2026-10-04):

#
# main.py -- this is the Raspberry Pi Pico W Band Selector controller.
#

__author__ = 'J. B. Otterson'
__copyright__ = 'Copyright 2022, 2026 J. B. Otterson N1KDO.'
__version__ = '0.1.27'  # 2026-10-04

#
# Copyright 2022, 2026 J. B. Otterson N1KDO.
#
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
import asyncio
import gc
import os
import sys
import time

from alcd import LCD
from button import Button
from config_data import ConfigData
from fourbits import FourBits
from gpio_pin import GPIO_Pin
from http_server import (HttpServer,
                         HTTP_STATUS_OK,
                         HTTP_STATUS_MOVED_PERMANENTLY,
                         HTTP_STATUS_BAD_REQUEST,
                         HTTP_VERB_GET,
                         HTTP_VERB_POST)

import micro_logging as logging
from ntp import get_ntp_time
from ringbuf_queue import RingbufQueue
import timer_manager
from udp_messages import (calculate_broadcast_address, ReceiveBroadcasts, RADIO_1_ANTENNA_OFFSET,
                          RADIO_2_ANTENNA_OFFSET, RADIO_NAMES_OFFSET, RADIO_NAMES_SIZE, ANTENNA_NAMES_OFFSET,
                          ANTENNA_NAMES_SIZE, ANTENNA_BANDS_OFFSET, ANTENNA_BANDS_SIZE, SWITCH_NAME_OFFSET)

from utils import milliseconds, upython, safe_int, num_bits_set, is_ipv4, is_hostname

if upython:
    import machine
    from picow_network import PicowNetwork
    try:
        from watchdog import Watchdog
    except ImportError:
        pass
    picow_network: PicowNetwork | None = None
else:
    from not_machine import machine
    picow_network: None = None


    def const(i):  # support micropython const() in cpython
        return i

import uaiohttpclient as aiohttp

BANDS = (b'NoBand', b'160M', b'80M', b'60M', b'40M', b'30M', b'20M', b'17M',
         b'15M', b'12M', b'10M', b'6M', b'2M', b'70cm', b'NoBand', b'NoBand')
MASKS = (0x0000, 0x0001, 0x0002, 0x0004, 0x0008, 0x0010, 0x0020, 0x0040, 0x0080, 0x0100, 0x0200, 0x0400, 0x800, 0x1000,
         0x0000, 0x0000)
# noinspection PyUnboundLocalVariable
_MIN_BAND = const(1)
_MAX_BAND = const(13)

# this list maps band indexes to the value of the 4-bit band select outputs.
# there are 11 valid outputs, 0000 -> 1010 (0-10), the other five map to NO BAND (0)
ELECRAFT_BAND_MAP = (3,  # 0000 -> 60M
                     1,  # 0001 -> 160M
                     2,  # 0010 -> 80M
                     4,  # 0011 -> 40M
                     5,  # 0100 -> 30M
                     6,  # 0101 -> 20M
                     7,  # 0110 -> 17M
                     8,  # 0111 -> 15M
                     9,  # 1000 -> 12M
                     10,  # 1001 -> 10M
                     11,  # 1010 ->  6M
                     0,  # 1011 -> invalid
                     0,  # 1100 -> invalid
                     0,  # 1101 -> invalid
                     0,  # 1110 -> invalid
                     0,  # 1111 -> invalid
                     )

# message IDs
_MSG_BTN_1 = const(1)
_MSG_BTN_2 = const(2)
_MSG_BTN_3 = const(3)
_MSG_BTN_4 = const(4)
_MSG_POWER_SENSE = const(10)
_MSG_NETWORK_CHANGE = const(20)
_MSG_NETWORK_UPDOWN = const(50)
_MSG_LCD_LINE0 = const(90)
_MSG_LCD_LINE1 = const(91)
_MSG_BAND_CHANGE = const(100)
_MSG_ANTENNA_RESPONSE = const(202)
_MSG_UDP_RESPONSE = const(203)
_MSG_UDP_TIMEOUT = const(204)

# http api status for failures
_API_STATUS_TIMEOUT = const(-1)
_API_STATUS_ERROR = const(-2)
_API_STATUS_READ_ERROR = const(-3)

# set up message queue
msgq = RingbufQueue(32)

# other I/O setup
onboard = machine.Pin('LED', machine.Pin.OUT, value=1)  # turn on right away
red_led = machine.Pin(0, machine.Pin.OUT, value=0)  # Red LED on GPIO0 / pin 1
blinky = machine.Pin(14, machine.Pin.OUT, value=0)  # diagnostic LED on GPIO14 / pin 19

# push buttons on display board on GPIO10-13
sw1 = machine.Pin(13, machine.Pin.IN, machine.Pin.PULL_UP)  # mode button input on GPIO13 / pin 17
sw2 = machine.Pin(12, machine.Pin.IN, machine.Pin.PULL_UP)  # mode button input on GPIO12 / pin 16
sw3 = machine.Pin(11, machine.Pin.IN, machine.Pin.PULL_UP)  # mode button input on GPIO11 / pin 15
sw4 = machine.Pin(10, machine.Pin.IN, machine.Pin.PULL_UP)  # mode button input on GPIO10 / pin 14

Button(sw1, msgq, (_MSG_BTN_1, 0), (_MSG_BTN_1, 1))  # SW1
Button(sw2, msgq, (_MSG_BTN_2, 0), (_MSG_BTN_2, 1))
Button(sw3, msgq, (_MSG_BTN_3, 0), (_MSG_BTN_3, 1))
Button(sw4, msgq, (_MSG_BTN_4, 0), (_MSG_BTN_4, 1))  # SW 4

# LCD display on display board on GPIO pins
# RW is hardwired to GPIO7,
machine.Pin(7, machine.Pin.OUT, value=0)  # this is the RW pin, hold it low.
light = machine.Pin(9, machine.Pin.OUT, value=1)  # GPIO9/pin 12, this is the backlight, so I can blink it.
lcd = LCD((8, 6, 5, 4, 3, 2), cols=20)

# radio interface on GPIO15-22
# auxbus = machine.Pin(15, machine.Pin.IN, machine.Pin.PULL_UP)  # AUXBUS data input on GPIO15 (maybe)
inhibit_pin = machine.Pin(16, machine.Pin.OUT, value=0)  # TX inhibit control on GPIO16

band0 = machine.Pin(17, machine.Pin.IN, machine.Pin.PULL_UP)  # BAND0 data input on GPIO17
band1 = machine.Pin(18, machine.Pin.IN, machine.Pin.PULL_UP)  # BAND1 data input on GPIO18
band2 = machine.Pin(19, machine.Pin.IN, machine.Pin.PULL_UP)  # BAND2 data input on GPIO19
band3 = machine.Pin(20, machine.Pin.IN, machine.Pin.PULL_UP)  # BAND3 data input on GPIO20
band_detector = FourBits([band3, band2, band1, band0], msgq, (_MSG_BAND_CHANGE, 0))
poweron_pin = machine.Pin(21, machine.Pin.OUT, value=0)  # power on control on GPIO21
powersense = machine.Pin(22, machine.Pin.IN, machine.Pin.PULL_UP)  # power sense input on GPIO22
GPIO_Pin(powersense, msgq, (_MSG_POWER_SENSE, 0), (_MSG_POWER_SENSE, 1))

timer_mgr = timer_manager.TimerManager()
udp_timeout_timer = -1

CONTENT_DIR = 'content/'

DEFAULT_SECRET = 'selector'
DEFAULT_SSID = 'selector'
DEFAULT_WEB_PORT = 80

# globals...
keep_running = True
current_antenna = -1
current_antenna_name = b'Unknown Antenna'
current_band_number = 0
radio_name = b'Unknown Rig'
antenna_names = []
antenna_bands = []
band_antennae = []  # list of antennas that could work on the current band.
network_connected = False
radio_number = 0
radio_power = False
switch_connected = False
switch_host = None
switch_name = b''
switch_timeouts = 0
receive_broadcasts = None
broadcast_receiver_task = None

# well-loved status messages
ui_pages = [[b'', b''], [b'', b'']]

# UI state machine data
_RADIO_DATA_PAGE = const(0)
_NETWORK_DATA_PAGE = const(1)

ui_page = _RADIO_DATA_PAGE
current_antenna_list_index = 0

config = ConfigData()

# http server
http_server = HttpServer(content_dir=CONTENT_DIR)


async def set_rtc_time():
    if picow_network is not None and time.time() < 1700000000:
        await get_ntp_time(dns_servers=picow_network.get_dns_servers())


async def api_response(resp, msg, q):
    """
    function waits for API response, enqueues message containing response
    :param resp: the HTTP response data from the API call
    :param msg: a "prototype" for the message to be returned.  a 2-tuple, (MSG_ID, payload)
    :param q: the message queue on which to enqueue the message
    :return: None
    """
    status = msg[1][0]
    try:
        payload = await resp.read()
    except Exception as ex:
        logging.exception('did not read payload', 'main:api_response', ex)
        payload = b'api read error'
        status = _API_STATUS_READ_ERROR
    if logging.should_log(logging.DEBUG):
        logging.debug(f'api call returned {payload}', 'main:api_response')
    data = (status, payload)  # copy the existing http status from the msg tuple
    new_msg = (msg[0], data)
    await q.put(new_msg)


async def call_api(url, msg, q):
    if logging.should_log(logging.DEBUG):
        logging.debug(f'calling api {url}', 'main:call_api')
    gc.collect()
    if upython and logging.should_log(logging.DEBUG):
        free = gc.mem_free()
        alloc = gc.mem_alloc()
        pct_free = free / (free + alloc) * 100
        logging.debug(f'{alloc} allocated, {free} free {pct_free:6.2f}% free.', 'main:call_api')
    t0 = milliseconds()
    try:
        resp = await asyncio.wait_for(aiohttp.request(b"GET", url), 0.5)
    except asyncio.TimeoutError:  # as ex:
        dt = milliseconds() - t0
        errmsg = b'timed out on api call to "%s" after %d ms' % (url, dt)
        logging.warning(errmsg, 'main:call_api')
        msg = (msg[0], (_API_STATUS_TIMEOUT, errmsg))
        await q.put(msg)
    except Exception as ex:
        dt = milliseconds() - t0
        errmsg = b'failed to execute api call to "%s" after %d ms' % (url, dt)
        logging.exception(errmsg, 'main:call_api', ex)
        msg = (msg[0], (_API_STATUS_ERROR, errmsg))
        await q.put(msg)
    else:
        http_status = resp.status
        if logging.should_log(logging.DEBUG):
            dt = milliseconds() - t0
            logging.debug(f'api call to {url} returned {http_status} after {dt} ms', 'main:call_api')
        msg = (msg[0], (http_status, b'no response'))
        asyncio.create_task(api_response(resp, msg, q))


async def call_select_antenna_api(new_antenna, msg, q):
    if logging.should_log(logging.INFO):
        logging.info(f'requesting antenna {new_antenna}', 'main:call_select_antenna_api')
    url = b'http://%s/api/select_antenna?radio=%d&antenna=%d' % (switch_host, radio_number, new_antenna)
    asyncio.create_task(call_api(url, msg, q))


# noinspection PyUnusedLocal
@http_server.route(b'/')
async def slash_callback(http, verb, args, reader, writer, request_headers=None):  # callback for '/'
    http_status = HTTP_STATUS_MOVED_PERMANENTLY
    bytes_sent = await http.send_simple_response(writer, http_status, None, None, ['Location: /status.html'])
    return bytes_sent, http_status


# noinspection PyUnusedLocal
@http_server.route(b'/api/config')
async def api_config_callback(http, verb, args, reader, writer, request_headers=None):  # callback for '/api/config'
    global config, switch_host, switch_name, radio_number
    if verb == HTTP_VERB_GET:
        response = config.get_data().copy()
        # response.pop('secret')  # do not return the secret
        response['secret'] = ''  # do not return the actual secret
        http_status = HTTP_STATUS_OK
        bytes_sent = await http.send_simple_response(writer, http_status, http.CT_APP_JSON, response)
    elif verb == HTTP_VERB_POST:
        errors = False
        problems = []
        log_level = args.get('log_level')
        if log_level is not None:
            log_level = log_level.strip().upper()
            if log_level in ['DEBUG', 'INFO', 'WARNING', 'ERROR', 'CRITICAL', 'NOTHING']:
                config['log_level'] = log_level
                logging.set_level(log_level)
            else:
                errors = True
                problems.append('log_level')
        web_port = args.get('web_port')
        if web_port is not None:
            web_port_int = safe_int(web_port, -2)
            if 1 <= web_port_int <= 65535:
                config['web_port'] = web_port_int
            else:
                errors = True
                problems.append('web_port')
        ssid = args.get('SSID')
        if ssid is not None:
            if 0 < len(ssid) <= 32:
                config['SSID'] = ssid
            else:
                errors = True
                problems.append('ssid')
        secret = args.get('secret')
        if secret is not None and len(secret) > 0:
            if 8 <= len(secret) < 64:
                config['secret'] = secret
            else:
                errors = True
                problems.append('secret')
        hostname = args.get('hostname')
        if hostname is not None:
            if 0 < len(hostname) <= 64:
                config['hostname'] = hostname
            else:
                errors = True
                problems.append('hostname')
        dhcp_arg = args.get('dhcp')
        if dhcp_arg is not None:
            dhcp = bool(safe_int(dhcp_arg, 0))
            config['dhcp'] = dhcp
        if not config.get('dhcp', True):
            ip_address = args.get('ip_address')
            if ip_address is not None:
                ip_address = ip_address.strip()
                if is_ipv4(ip_address):
                    config['ip_address'] = ip_address
                else:
                    errors = True
                    problems.append('ip_address')
            netmask = args.get('netmask')
            if netmask is not None:
                netmask = netmask.strip()
                if is_ipv4(netmask):
                    config['netmask'] = netmask
                else:
                    errors = True
                    problems.append('netmask')
            gateway = args.get('gateway')
            if gateway is not None:
                gateway = gateway.strip()
                if is_ipv4(gateway):
                    config['gateway'] = gateway
                else:
                    errors = True
                    problems.append('gateway')
            dns_server = args.get('dns_server')
            if dns_server is not None:
                dns_server = dns_server.strip()
                if is_ipv4(dns_server):
                    config['dns_server'] = dns_server
                else:
                    errors = True
                    problems.append('dns_server')
        switch_ip = args.get('switch_ip')
        if switch_ip is not None:
            switch_ip = switch_ip.strip()
            # the switch may be addressed by hostname (default 'localhost') or IP.
            if is_hostname(switch_ip):
                switch_host = switch_ip.encode()
                config['switch_ip'] = switch_ip
            else:
                errors = True
                problems.append('switch_ip')
        switch_name_arg = args.get('switch_name')
        if switch_name_arg is not None:
            # The name is matched against the controller's 64-byte hostname field in
            # the status broadcast, so anything longer can never match (and would put
            # every datagram in the 'foreign' bucket -> silent 'no switch' state).
            if 0 < len(switch_name_arg) <= 64:
                config['switch_name'] = switch_name_arg
                switch_name = config.get_bytes('switch_name')
                if receive_broadcasts is not None:
                    receive_broadcasts.set_switch_name(switch_name)
            else:
                errors = True
                problems.append('switch_name')
        cfg_auto_on = args.get('auto_on')
        if cfg_auto_on is not None:
            auto_on = bool(safe_int(cfg_auto_on, 0))
            config['auto_on'] = auto_on
        cfg_radio_number = args.get('radio_number')
        if cfg_radio_number is not None:
            cfg_radio_number = safe_int(cfg_radio_number, -1)
            if 1 <= cfg_radio_number <= 2:
                radio_number = cfg_radio_number
                config['radio_number'] = cfg_radio_number
            else:
                errors = True
                problems.append('radio_number')
        if not errors:
            response = b'ok\r\n'
            http_status = HTTP_STATUS_OK
            bytes_sent = await http.send_simple_response(writer, http_status, http.CT_TEXT_TEXT, response)
        else:
            response = b'parameter out of range\r\n'
            logging.error(f'problems {problems}', 'main:api_config_callback')
            http_status = HTTP_STATUS_BAD_REQUEST
            bytes_sent = await http.send_simple_response(writer, http_status, http.CT_TEXT_TEXT, response)
    else:
        response = b'GET or PUT only.'
        http_status = HTTP_STATUS_BAD_REQUEST
        bytes_sent = await http.send_simple_response(writer, http_status, http.CT_TEXT_TEXT, response)
    return bytes_sent, http_status


# noinspection PyUnusedLocal
@http_server.route(b'/api/restart')
async def api_restart_callback(http, verb, args, reader, writer, request_headers=None):
    global keep_running
    config.flush()
    if upython:
        keep_running = False
        response = b'ok\r\n'
        http_status = HTTP_STATUS_OK
        bytes_sent = await http.send_simple_response(writer, http_status, http.CT_TEXT_TEXT, response)
    else:
        http_status = HTTP_STATUS_BAD_REQUEST
        response = b'not permitted except on PICO-W'
        bytes_sent = await http.send_simple_response(writer, http_status, http.CT_TEXT_TEXT, response)
    return bytes_sent, http_status


@http_server.route(b'/api/status')
async def api_status_callback(http, verb, args, reader, writer, request_headers=None):  # '/api/status'
    """
    wants to have message looking like this:
    {"lcd_lines": ["Elecraft K3 No Power","    6 Meter Yagi    "],
    "radio_power": false
    "switch_connected": true
     }
    """
    http_status = HTTP_STATUS_OK
    # let send_simple_response's dict path json.dumps() the payload: the LCD
    # lines carry antenna names from the switch controller that may contain
    # quotes or backslashes and must be escaped.
    r = {
        'lcd_lines': [lcd[0].decode(), lcd[1].decode()],
        'radio_power': radio_power,
        'switch_connected': switch_connected,
    }
    bytes_sent = await http.send_simple_response(writer, http_status, http.CT_APP_JSON, r)

    return bytes_sent, http_status


@http_server.route(b'/api/power_on_radio')
async def api_power_on_radio_callback(http, verb, args, reader, writer, request_headers=None):
    await power_on()
    r = {
        'lcd_lines': [lcd[0].decode(), lcd[1].decode()],
        'radio_power': radio_power,
        'switch_connected': switch_connected,
    }
    http_status = HTTP_STATUS_OK
    bytes_sent = await http.send_simple_response(writer, http_status, http.CT_APP_JSON, r)
    return bytes_sent, http_status


@http_server.route(b'/api/button')
async def api_button_press(http, verb, args, reader, writer, request_headers=None):
    response = b'Invalid button number.\r\n'
    http_status = HTTP_STATUS_BAD_REQUEST
    button = args.get('button')
    if button is not None:
        button_num = safe_int(button, -1)
        if button_num == 1:
            await msgq.put((_MSG_BTN_1, 0))
            http_status = HTTP_STATUS_OK
            response = b'ok\r\n'
        elif button_num == 2:
            await msgq.put((_MSG_BTN_2, 0))
            http_status = HTTP_STATUS_OK
            response = b'ok\r\n'
        elif button_num == 3:
            await msgq.put((_MSG_BTN_3, 0))
            http_status = HTTP_STATUS_OK
            response = b'ok\r\n'
        elif button_num == 4:
            await msgq.put((_MSG_BTN_4, 0))
            http_status = HTTP_STATUS_OK
            response = b'ok\r\n'
    bytes_sent = await http.send_simple_response(writer, http_status, http.CT_TEXT_TEXT, response)
    return bytes_sent, http_status


def find_band_antennae(new_band_number: int):
    mask = MASKS[new_band_number]
    candidates = [(num_bits_set(antenna_bands[i]), i)
                  for i in range(len(antenna_bands))
                  if mask & antenna_bands[i]]
    candidates.sort()  # sort by bit-count (fewest shared bands first)
    return [i for _, i in candidates]


def set_inhibit(inhibit):
    inhibit_pin.value(inhibit)
    red_led.value(inhibit)


async def power_on():
    poweron_pin.on()
    await asyncio.sleep(0.1)
    poweron_pin.off()
    await asyncio.sleep(0.5)


async def new_band(new_band_number):
    global band_antennae, current_antenna_list_index
    if new_band_number == 0:
        logging.warning('new band with invalid band number')
        return
    logging.info(b'new band: ' + BANDS[new_band_number], 'main:new_band')
    await update_ui_page(_RADIO_DATA_PAGE, b'%s %s' % (radio_name, BANDS[new_band_number]), None)
    set_inhibit(1)
    band_antennae = find_band_antennae(new_band_number)
    if len(band_antennae) == 0:
        current_antenna_list_index = -1
        logging.warning(f'no antenna available for band {BANDS[new_band_number]}', 'main:new_band')
        #                                           '12345678901234567890'
        await update_ui_page(_RADIO_DATA_PAGE, None, '*No Antenna for Band*')
    else:
        if switch_connected:
            logging.info(f'new band: {BANDS[new_band_number]} got band_antennae {band_antennae}', 'main:new_band')
            await update_ui_page(_RADIO_DATA_PAGE, None, b'Requesting Antenna')
            current_antenna_list_index = 0
            await call_select_antenna_api(band_antennae[current_antenna_list_index] + 1,
                                          (_MSG_ANTENNA_RESPONSE, (0, '')), msgq)
        else:
            logging.warning('band changed but switch is not connected', 'main:new_band')
            # do not need to update 'radio' display, it should already indicate that the switch is not connected.


async def change_band_antenna(up=True):
    global current_antenna_list_index
    logging.info(f'change_band_antenna(up={up})', 'main:change_band_antenna')
    if len(band_antennae) <= 1:
        return False
    if up:
        current_antenna_list_index += 1
        if current_antenna_list_index >= len(band_antennae):
            current_antenna_list_index = 0
    else:  # down, yeah
        current_antenna_list_index -= 1
        if current_antenna_list_index < 0:
            current_antenna_list_index = len(band_antennae) - 1
    await call_select_antenna_api(band_antennae[current_antenna_list_index] + 1, (_MSG_ANTENNA_RESPONSE, (0, '')), msgq)
    return True
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

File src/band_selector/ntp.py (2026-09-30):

#
# ntp.py -- set pico time from NTP
#
# Copyright 2024, 2025, 2026, J. B. Otterson N1KDO.
#
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
__author__ = 'J. B. Otterson'
__copyright__ = 'Copyright 2024, 2025, 2026 J. B. Otterson N1KDO.'
__version__ = '0.1.3'  # 2026-09-30

#
# All network I/O in this module is async-safe: sockets are non-blocking and the
# code yields to the asyncio event loop while waiting, so a slow or blackholed
# DNS/NTP server can never starve the watchdog feeder task.  (MicroPython's
# asyncio has no UDP/DatagramProtocol support, so we poll a non-blocking socket
# with short loop yields instead.)
#
# Host names are resolved with a minimal RFC 1035 A-record client that queries
# the port-53 DNS server(s) supplied by the caller -- no synchronous
# socket.getaddrinfo() anywhere.
#

import asyncio
import random
import socket
import struct
import sys
import time

_IS_MICROPYTHON = sys.implementation.name == 'micropython'

if _IS_MICROPYTHON:
    from machine import RTC
    _rtc = RTC()
    from time import ticks_ms, ticks_diff
    import micro_logging as logging
    from asyncio import TimeoutError  # micropython has no builtin TimeoutError
else:
    _rtc = None
    def const(i):
        return i
    def ticks_ms():
        return int(time.monotonic() * 1000)
    def ticks_diff(a, b):
        return a - b
    import micro_logging as logging  # stdlib logging.exception() has a different signature
    from asyncio.exceptions import TimeoutError  # same class as the builtin on 3.11+

_UNIX_EPOCH = const(2208988800)  # 1970-01-01 00:00:00
_NTP_PORT = const(123)
_DNS_PORT = const(53)
_BUF_SIZE = const(1024)
_NTP_MSG = b'\x1b' + b'\0' * 47
_NTP_TIMEOUT_MS = const(2000)   # per NTP server; well inside the watchdog budget
_DNS_TIMEOUT_MS = const(2000)   # per DNS server
_DNS_POLL_MS = const(50)        # non-blocking recv poll interval
_STRUCT_FORMAT = '!12I'


# ---------------------------------------------------------------------------
# Minimal RFC 1035 DNS client (A records only).
# ---------------------------------------------------------------------------

def _is_ipv4(s):
    parts = s.split('.')
    if len(parts) != 4:
        return False
    for p in parts:
        if not p.isdigit() or int(p) > 255:
            return False
    return True


def _encode_dns_name(name):
    out = bytearray()
    for label in name.split('.'):
        lb = label.encode()
        if len(lb) > 63:
            raise ValueError('DNS label too long')
        out.append(len(lb))
        out.extend(lb)
    out.append(0)
    return bytes(out)


def _build_a_query(txid, host):
    # header: ID, flags=RD, QD=1, AN=NS=AR=0; question: name, TYPE=A(1), CLASS=IN(1)
    return (struct.pack('!HHHHHH', txid, 0x0100, 1, 0, 0, 0)
            + _encode_dns_name(host)
            + struct.pack('!HH', 1, 1))


def _read_dns_name(data, off):
    """Walk a (possibly compressed) DNS name.  Returns (name_str, new_offset)."""
    labels = []
    end = None
    pointers = 0
    while True:
        if off >= len(data):
            raise ValueError('truncated DNS name')
        l = data[off]
        if l & 0xC0:
            if off + 1 >= len(data):
                raise ValueError('truncated DNS name pointer')
            pointers += 1
            if pointers > 20:  # real names use far fewer; more implies a cycle.
                raise ValueError('too many DNS name pointers (cycle?)')
            if end is None:
                # a pointer means the name "ends" after this 2-byte pointer
                end = off + 2
            off = ((l & 0x3F) << 8) | data[off + 1]
        elif l == 0:
            break
        else:
            if l > 63 or off + 1 + l > len(data):
                raise ValueError('bad DNS label')
            labels.append(bytes(data[off + 1:off + 1 + l]))
            off += 1 + l
    return b'.'.join(labels).decode(), (end if end is not None else off + 1)


def _parse_a_response(txid, data):
    """Return the first IPv4 A record as a dotted-quad string.

    Raises LookupError if the response contains no A record, ValueError if the
    response is malformed or does not match txid.
    """
    if len(data) < 12:
        raise ValueError('DNS response too short')
    rid, flags, qdcount, ancount = struct.unpack('!4H', data[:8])
    if rid != txid:
        raise ValueError('DNS transaction id mismatch')
    if not (flags & 0x8000):
        raise ValueError('DNS response QR bit not set')
    rcode = flags & 0x0F
    off = 12
    for _ in range(qdcount):
        _, off = _read_dns_name(data, off)
        off += 4  # qtype + qclass
    for _ in range(ancount):
        _, off = _read_dns_name(data, off)
        if off + 10 > len(data):
            raise ValueError('truncated DNS record')
        rtype, rclass = struct.unpack('!HH', data[off:off + 4])
        off += 8  # type, class, ttl
        rdlen = struct.unpack('!H', data[off:off + 2])[0]
        off += 2
        if rtype == 1 and rclass == 1 and rdlen == 4:
            # MicroPython's socket has no inet_ntoa; format the 4 octets directly.
            ip = data[off:off + 4]
            return '%d.%d.%d.%d' % (ip[0], ip[1], ip[2], ip[3])
        off += rdlen
    raise LookupError('no A record in DNS response (rcode=%d)' % rcode)


async def _recvfrom_async(sock, timeout_ms):
    """Receive one datagram from a non-blocking socket, yielding to the event
    loop until data arrives or timeout_ms elapses.  Returns the datagram bytes.
    Raises TimeoutError on expiry."""
    deadline = ticks_ms() + timeout_ms
    while True:
        try:
            return sock.recvfrom(_BUF_SIZE)[0]
        except OSError:
            # EAGAIN/EWOULDBLOCK: no datagram yet.  Other OSErrors are treated
            # the same and will run out the clock; bounded by the deadline.
            if ticks_diff(deadline, ticks_ms()) <= 0:
                raise TimeoutError('UDP recv timed out')
            await asyncio.sleep(_DNS_POLL_MS / 1000)
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

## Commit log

2024-09-15 sanity commit
    [BandSelector.kicad_pcb, BandSelector.kicad_sch]
2024-09-15 better, better.
    [BandSelector.kicad_pcb, BandSelector.kicad_sch]
2024-09-22 circuit changes.
    connector is placed.
    [10090926-P154XLF.step, 75915-416LF.step, BandSelector.kicad_pcb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]
2024-09-26 use Peter Hinch's lcd driver.
2024-09-27 move auxbus listen to TP configure pushbuttons to send events.
    [BandSelector.kicad_pcb, BandSelector.kicad_sch]
2024-10-25 software, meet hardware.
    [BandSelector.kicad_pcb, BandSelector.kicad_sch]
2024-10-26 power up radio works
2024-10-26 schematic update, get 3d images
    [BandSelector.kicad_pcb, BandSelector.kicad_sch]
2024-10-30 add display board
2024-10-30 update BOM
2024-11-10 buttons short and long press
    [gpio_pin.py, loader.py, main.py]
2024-11-16 features and bugs
    next/prior antenna per band working
    hostname can be configured from web ui
    [alcd.py, main.py]
2024-11-30 update message when radio power is off
2024-12-01 update schematic PDF files
    they are in color now.
    [display-board.kicad_sch]
2024-12-14 switch to manifest-driven loader
2024-12-15 indicate that switch is inaccessible, part 1
2024-12-15 remove obsolete reset button support.
2024-12-28 fix pop & etc.
    [main.py]
2024-12-28 Display band despite missing switch
    plus some import cleanups
    [alcd.py, main.py]
2024-12-29 change LED color in labels only.
    [BandSelector.kicad_sch]
2024-12-29 close uaiohttpclient streams properly
    to attempt to prevent resource leaks
    [main.py, uaiohttpclient.py]
2024-12-29 update pdf of schematic
2024-12-31 reset dirty earlier
    address race condition that causes a new row in < 20 ms to not be displayed.
    [alcd.py]
2025-01-04 try harder to get alternate antenna
2025-01-05 update BOM with prices
    add more explanation to README.md
2025-01-09 make switch detection more robust
2025-01-18 add watchdog timer
2025-01-18 add power up radio button
2025-01-19 Revert "common code to mpy_common"
    This reverts commit 88f54c2f6fc7813e11f3ba3c98a1dd2b69ef4cb3.
    [loader.py]
2025-01-27 cleanups and fix heinous bug
    [main.py]
2025-03-18 use shorter status api call
    [main.py]
2025-03-20 more async http server
    fix up constants
    uaiohttpclient changes
    [main.py, uaiohttpclient.py]
2025-04-24 make keyboard interrupt more graceful
2025-08-03 set access point mode only if switch 1 is held during powerup
2025-08-04 ui changes
    show number of additional antennas when available
2025-08-17 auto-power on the K3/4 radio feature
2025-08-22 blink onboard LED.
    about 5 hz.
2025-08-23 blink diagnostic LED.
    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
2025-09-24 clean up TODOs and FIXMEs
    [main.py, udp_messages.py]
2025-09-26 set inhibit when switch becomes unavailable
2025-11-24 more info about antenna selection
2026-01-01 reset should tolerate more exception classes
    [loader.py]
2026-01-07 fix mobile device layout
2026-05-18 add support the four device buttons to the web UI
2026-05-20 fix error logging to use logging
    [ntp.py]
2026-07-05 adjust slots dunder
2026-07-06 fix copy of bytes buffer
    [udp_messages.py]
2026-07-07 fix inhibit on UDP message.
    [main.py]
2026-10-02 change AP mode to button held at startup
2026-10-04 reset headers on redirect
    [uaiohttpclient.py]
